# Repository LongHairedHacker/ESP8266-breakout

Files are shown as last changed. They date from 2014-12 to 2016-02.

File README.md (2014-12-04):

ESP8266 Breakout Chaos InKL Version
===================================

Slightly modified version of limpkins ESP8266 breakout board.
See: http://www.limpkin.fr/index.php?post/2014/11/27/A-Development-Board-for-the-ESP8266-03 for the original files.

Licenses
--------
Anything in the folder libs/smisitoto_eu/ is taken from http://smisioto.no-ip.org/elettronica/kicad/kicad-en.htm The files are made avaible under the Creative Commons license rev2.5 Attribution-ShareAlike. (see https://creativecommons.org/licenses/by-sa/2.5/)

The Chaos InKL logo is licensed CC BY-NC-SA 3.0.

The exploding open hardware logo (artwork/hacker_logo.mod) is my private logo,
you are not allowed to use it on your own design and you should therefore remove it,
after forking this repository.

All remaining files repository are under the CERN Open Hardware Licence v1.2.

Thanks to limpkin for the initial design.

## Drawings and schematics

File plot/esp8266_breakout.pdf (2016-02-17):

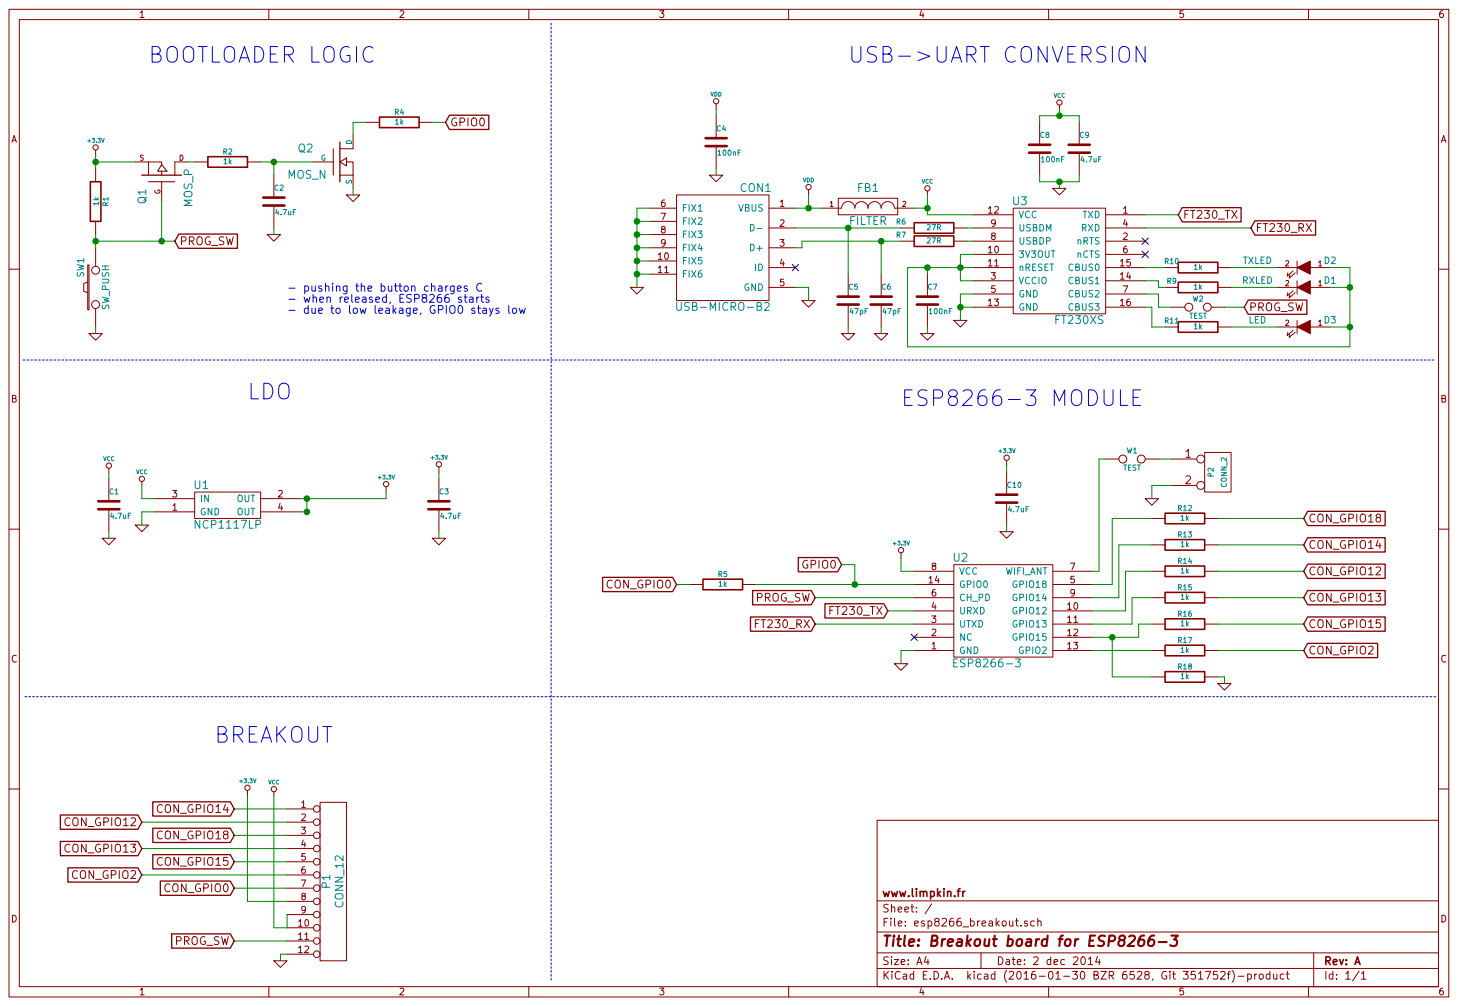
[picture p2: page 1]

- pushing the button charges C
- when released, ESP8266 starts
- due to low leakage, GPIO0 stays low

Id: 1/1 Title: Breakout board for ESP8266-3

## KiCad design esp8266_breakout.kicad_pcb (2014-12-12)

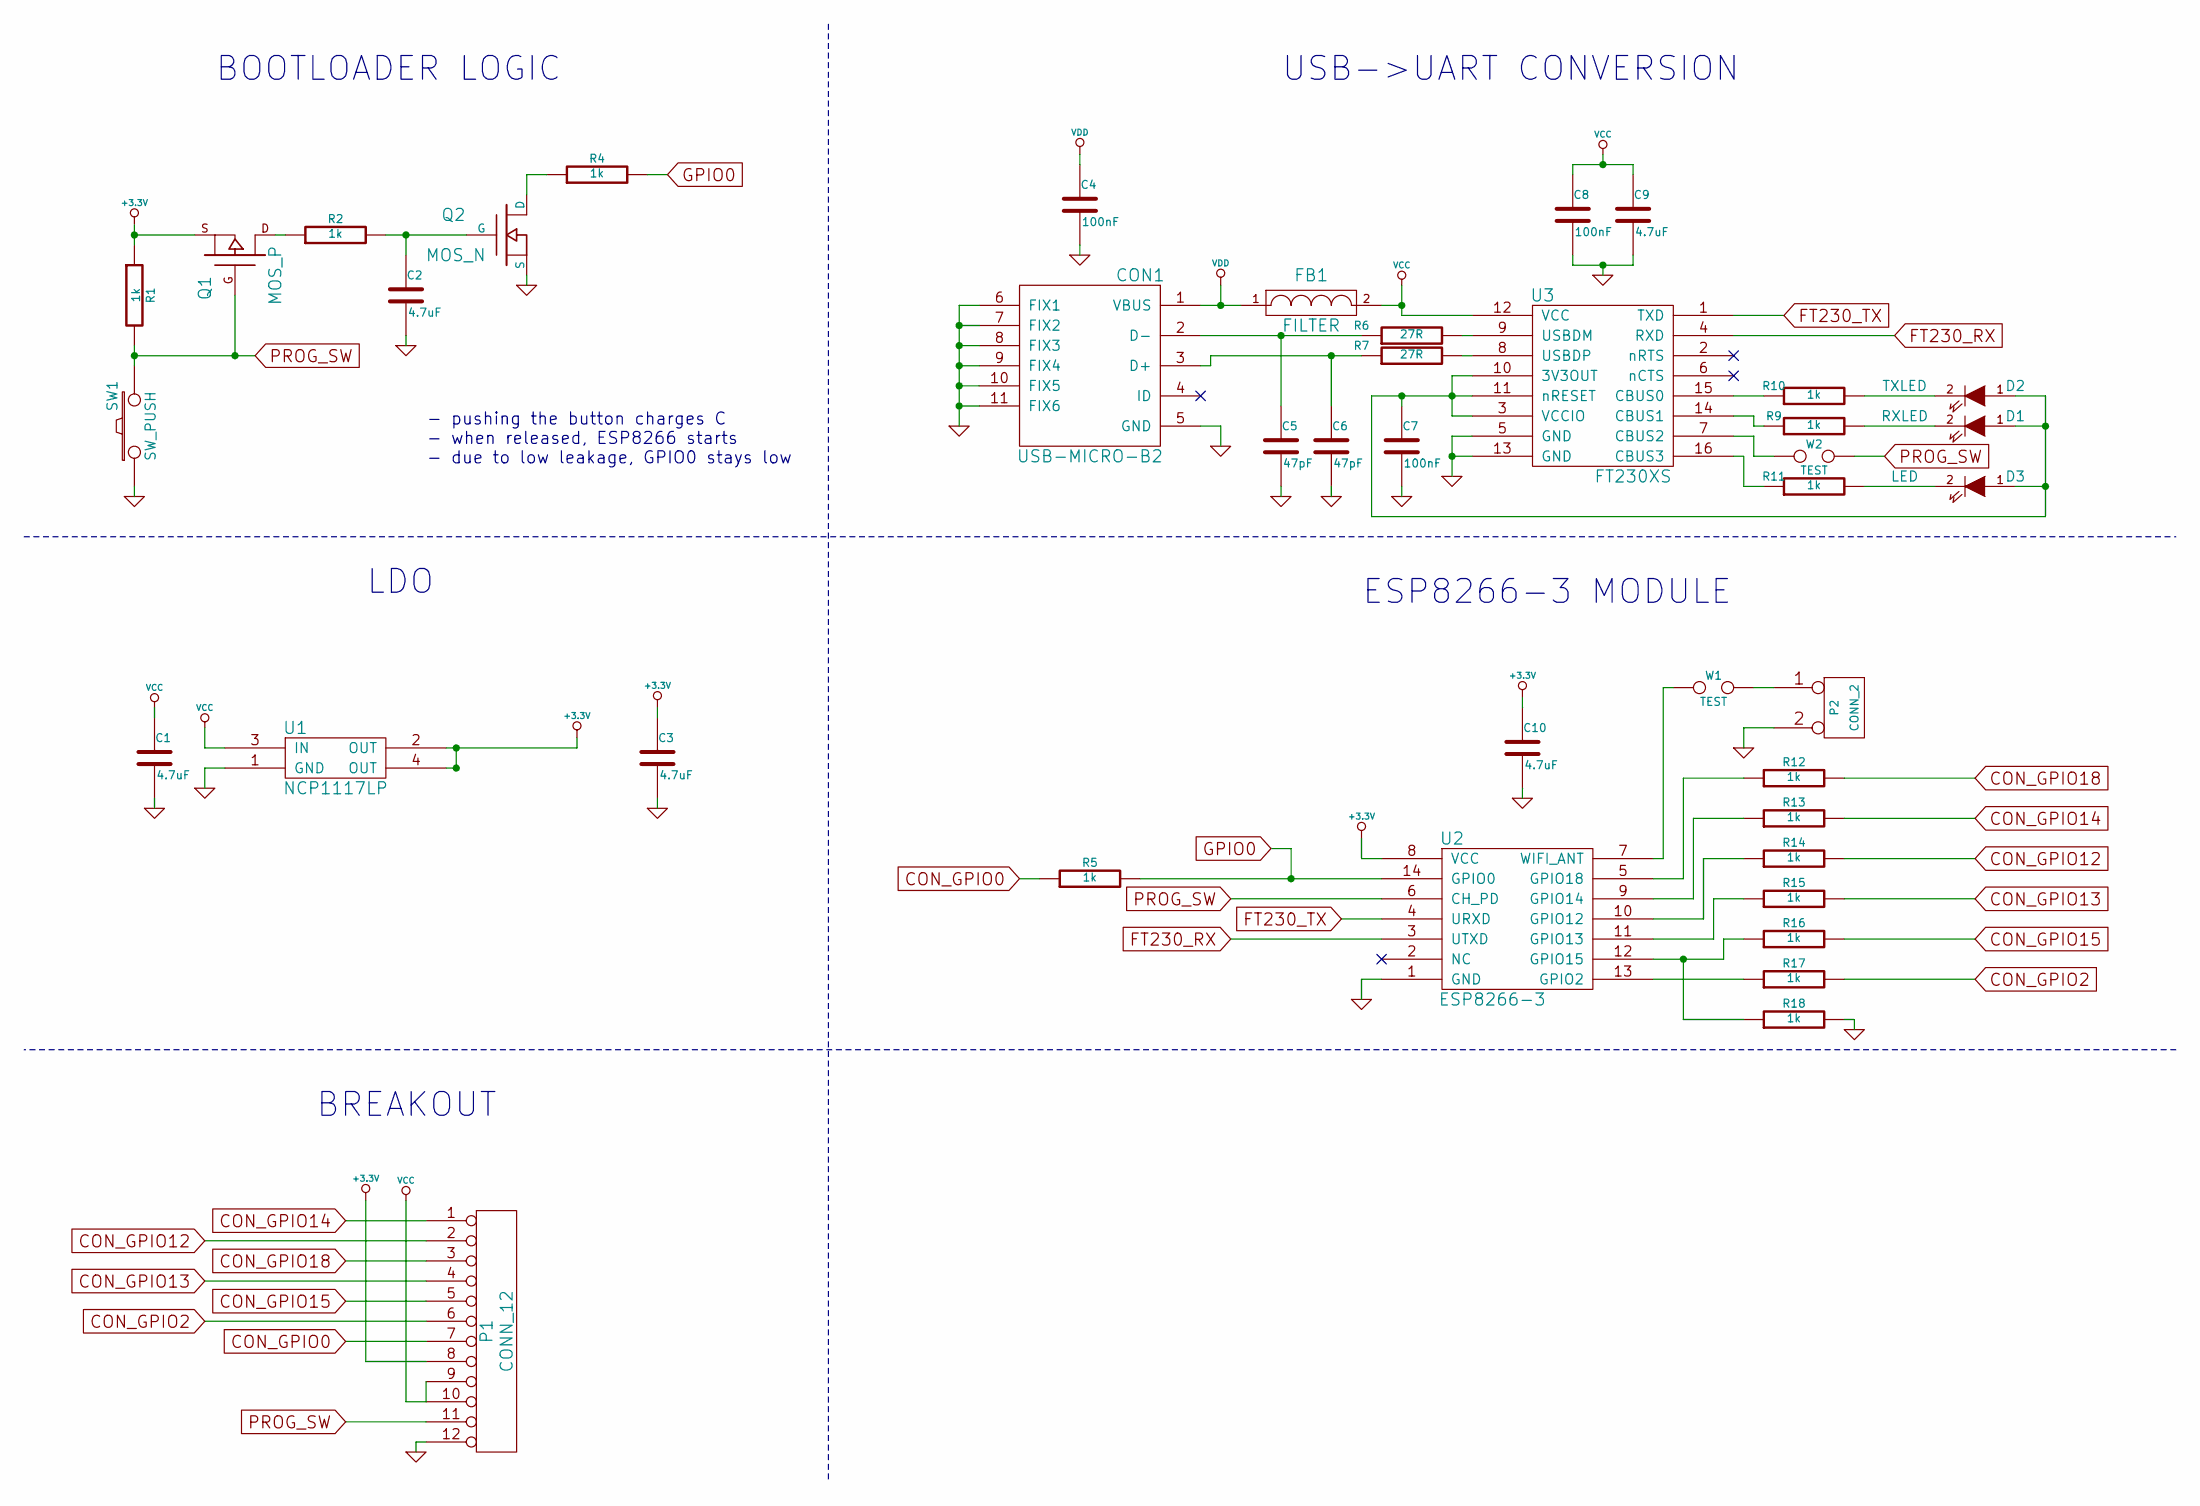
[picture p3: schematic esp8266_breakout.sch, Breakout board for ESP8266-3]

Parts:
C1, C2, C3, C9, C10: 4.7uF
C4, C7, C8: 100nF
C5, C6: 47pF
CON1: USB-MICRO-B2
D1: RXLED
D2: TXLED
D3: LED
FB1: FILTER
P1: CONN_12
P2: CONN_2
Q1: MOS_P
Q2: MOS_N
R1, R2, R4, R5, R9, R10, R11, R12, R13, R14, R15, R16, R17, R18: 1k
R6, R7: 27R
SW1: SW_PUSH
U1: NCP1117LP
U2: ESP8266-3
U3: FT230XS
W1, W2: TEST

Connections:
+3.3V: C3.1, C10.1, P1.8, Q1.S, R1.1, U1.2 (OUT), U1.4 (OUT), U2.8 (VCC)
CON_GPIO0: P1.7, R5.1
CON_GPIO2: P1.6, R17.2
CON_GPIO12: P1.2, R14.2
CON_GPIO13: P1.4, R15.2
CON_GPIO14: P1.1, R13.2
CON_GPIO15: P1.5, R16.2
CON_GPIO18: P1.3, R12.2
FT230_RX: U2.3 (UTXD), U3.4 (RXD)
FT230_TX: U2.4 (URXD), U3.1 (TXD)
GND: C1.2, C2.2, C3.2, C4.2, C5.2, C6.2, C7.2, C8.2, C9.2, C10.2, CON1.5 (GND), CON1.6 (FIX1), CON1.7 (FIX2), CON1.8 (FIX3), CON1.9 (FIX4), CON1.10 (FIX5), CON1.11 (FIX6), P1.12, P2.2 (PM), Q2.S, R18.2, SW1.1, U1.1 (GND), U2.1 (GND), U3.5 (GND), U3.13 (GND)
GPIO0: R4.2, R5.2, U2.14 (GPIO0)
unnamed: C5.1, CON1.2 (D-), R6.1
unnamed: C6.1, CON1.3 (D+), R7.1
unnamed: R7.2, U3.8 (USBDP)
unnamed: R6.2, U3.9 (USBDM)
unnamed: R17.1, U2.13 (GPIO2)
unnamed: C7.1, D1.1 (A), D2.1 (A), D3.1 (A), U3.3 (VCCIO), U3.10 (3V3OUT), U3.11 (nRESET)
unnamed: D3.2 (K), R11.2
unnamed: D1.2 (K), R9.2
unnamed: Q2.D, R4.1
unnamed: C2.1, Q2.G, R2.2
unnamed: Q1.D, R2.1
unnamed: U2.7 (WIFI_ANT), W1.1
unnamed: U3.7 (CBUS2), W2.1
unnamed: R11.1, U3.16 (CBUS3)
unnamed: R9.1, U3.14 (CBUS1)
unnamed: R10.1, U3.15 (CBUS0)
unnamed: P2.1, W1.2
unnamed: D2.2 (K), R10.2
unnamed: R14.1, U2.10 (GPIO12)
unnamed: R12.1, U2.5 (GPIO18)
unnamed: R13.1, U2.9 (GPIO14)
unnamed: R15.1, U2.11 (GPIO13)
unnamed: R16.1, R18.1, U2.12 (GPIO15)
PROG_SW: P1.11, Q1.G, R1.2, SW1.2, U2.6 (CH_PD), W2.2
VCC: C1.1, C8.1, C9.1, FB1.2, P1.9, P1.10, U1.3 (IN), U3.12 (VCC)
VDD: C4.1, CON1.1 (VBUS), FB1.1

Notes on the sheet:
- pushing the button charges C - when released, ESP8266 starts - due to low leakage, GPIO0 stays low
BOOTLOADER LOGIC
USB->UART CONVERSION
LDO
ESP8266-3 MODULE
BREAKOUT

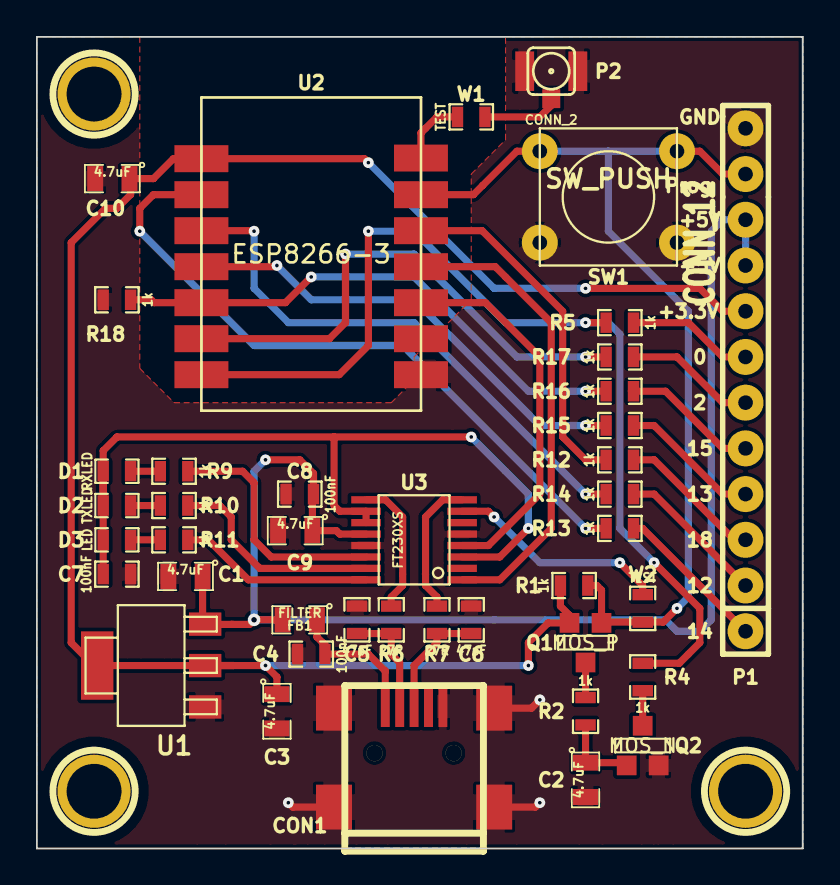
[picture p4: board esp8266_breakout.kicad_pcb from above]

Board: 2 copper layers, 42.5 x 45.1 mm, 44 parts (0 on the bottom side), 38 nets.

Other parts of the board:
1PIN, 1PIN#2, 1PIN#3: P***; 1pin

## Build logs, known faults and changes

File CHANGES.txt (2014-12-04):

Changes
=======

limpking
--------
- Original schematic and board layout
- See: http://www.limpkin.fr/index.php?post/2014/11/27/A-Development-Board-for-the-ESP8266-03

LongHairedHacker
----------------
- Chaos InKL Version
- Added connector for external antenna
- Changed some parts for easier sourcing
- Changed resistor network to individual resistors to allow individual resistance values
- Added mounting holes

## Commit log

2014-12-02 Starting reworking for ordering pcbs
    [esp8266_breakout.kicad_pcb]
2014-12-02 Finished first reworked layout version
    [esp8266_breakout.kicad_pcb]
2014-12-02 Added ufl connector cleaned up schematic
    [esp8266_breakout.kicad_pcb, esp8266_breakout.sch]
2014-12-04 Added logos and fancy silkscreen
    [esp8266_breakout.kicad_pcb]
2014-12-04 Added version and github url
    [esp8266_breakout.kicad_pcb]
2014-12-05 Removed french layer names ... because they were french
    [esp8266_breakout.kicad_pcb]
2014-12-09 Fixed footprints
    [esp8266_breakout.csv, esp8266_breakout.kicad_pcb]
2014-12-12 Final adjustments for Version 1.0 Generated gerbers
    [esp8266_breakout-B_Cu.gbl, esp8266_breakout-B_Mask.gbs, esp8266_breakout-B_Paste.gbp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]
